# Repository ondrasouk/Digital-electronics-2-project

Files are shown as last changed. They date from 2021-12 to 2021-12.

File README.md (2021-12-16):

# WATER TANK CONROLLER

### Team members

* Ondřej Soukeník (responsible for LCD keypad, MENU)
* Pavel Vaněk (responsible for Sensors)
* Michaela Ryšavá (responsible for RTC, Main file)
* Zdeňka Varmužová (responsible for Documentation)

Link to this file in your GitHub repository:

[https://github.com/ondrasouk/Digital-electronics-2-project](https://github.com/ondrasouk/Digital-electronics-2-project)

### Table of contents

* [Project objectives](#objectives)
* [Hardware description](#hardware)
* [Libraries description](#libs)
* [Main application](#main)
* [Video](#video)
* [References](#references)

## Project objectives

* the task:
    * Water tank controller. The following can be used: water level measurement, pump control, rain sensor and others.
    * [Link](https://github.com/tomas-fryza/Digital-electronics-2/tree/master/Labs/project) to the task.

* to do:
    * Preparation
        * [x] Block structure design
        * [x] The split of work
    * Realization
        * [x] Use of sensors
        * [x] Individual blocks of code
        * [x] Verification of the functionality
        * [x] Generating HEX file
    * Presentation
        * [x] Documentation
        * [x] Discussion of results
        * [x] Video presentation

* done:
    * Irrigation system. Water level - controlling sensor is placed in the tank and measures the water level (5 levels). Sensor for measuring soil moisture is placed in a soil and both send data to control logic, where are evaluated. If there is enough water in the tank and soil moisture is under specific value, water pump is activated. After certain time period another measuring is made. User can choose from three modes of irrigation. More info about the system is in the [video](https://youtu.be/Qcah5Nm7IAs).

## Hardware description

The solution is designed on an Arduino Uno board with sensors and a water pump connected to external pins.

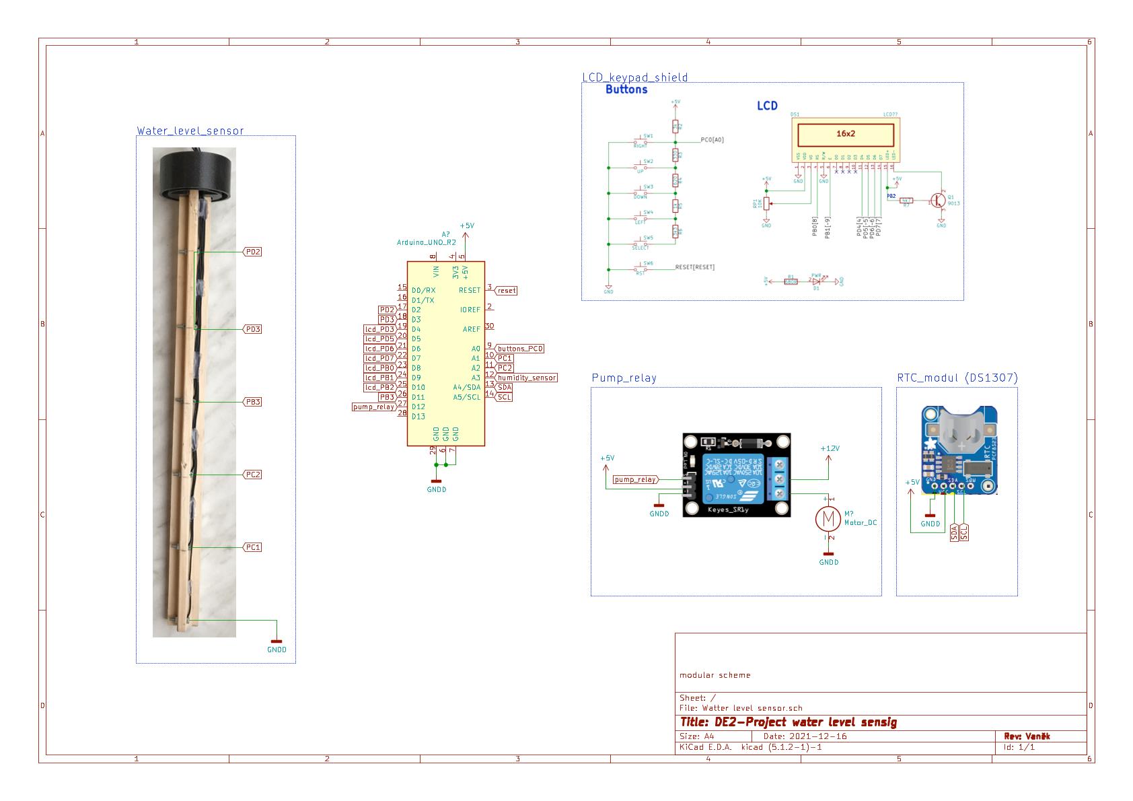
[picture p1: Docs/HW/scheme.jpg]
Scheme of connection


### Arduino Uno board 
The project is made for application on an Adruino Uno board with ATmega328P. 
[Arduino Uno board](Docs/arduino_shield.pdf)

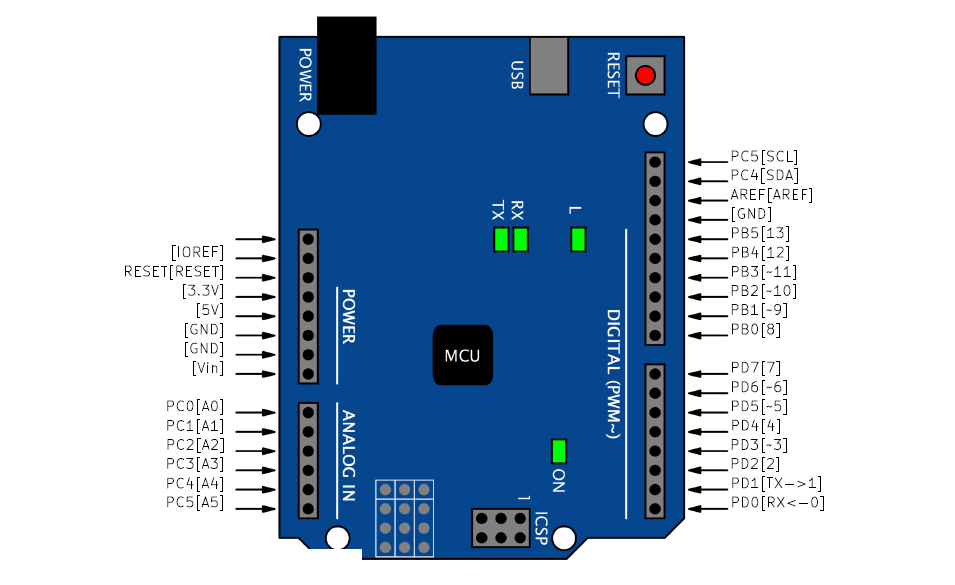
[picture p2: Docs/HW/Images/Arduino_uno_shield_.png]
Arduino_uno_board


For more informations see [hardware documentation](Docs/HW/readme.md).

### LCD keypad Shield
LCD and buttons are used for moving in the menu and displaying measured values. The LCD keypad shield is compatible with Arduino board.
[LCD keypad Shield](Docs/arduino_shield.pdf)
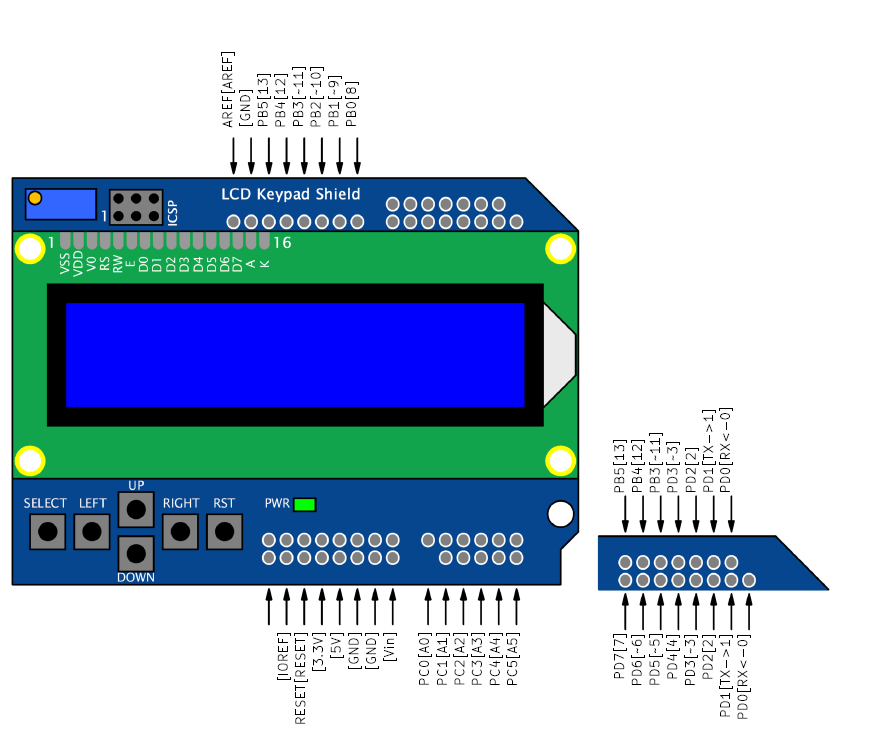
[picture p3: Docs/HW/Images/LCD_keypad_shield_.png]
LCD_keypad_shield


For more informations see [hardware documentation](Docs/HW/readme.md).

### Water lever sensor
The solution contains five sensors working on a resistive basis, which are placed on a panel. The top of the panel is attached to the lid of a canister with water. Six wires are brought out of the main board to the panel. One is for the reference (ground), other five are each in different height. The sensor contact surfaces are stainless steel screws placed on the panel. 

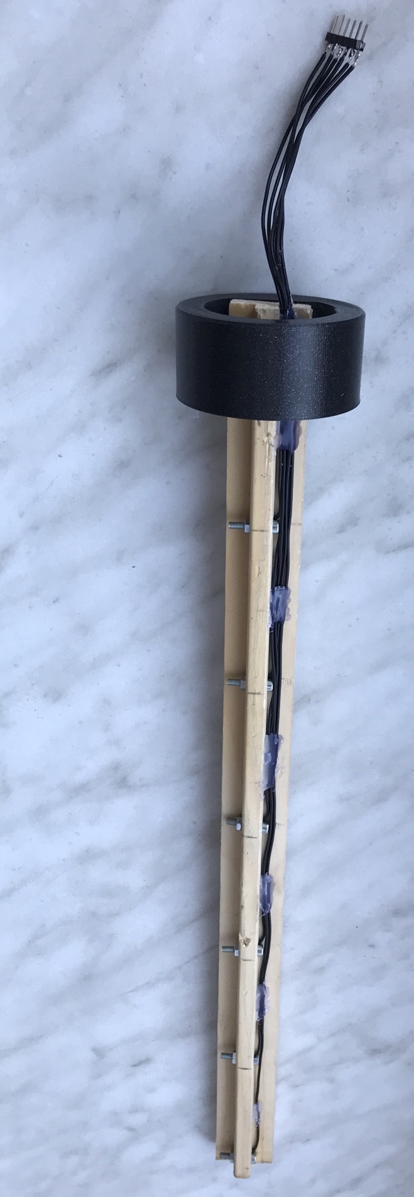
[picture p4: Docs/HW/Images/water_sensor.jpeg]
Water_level_sensor


For more informations see [hardware documentation](Docs/HW/readme.md).

### Soil moisture sensor
The sensor is based on different conductivities of the soil according to the moisture of the soil. Two wires are connected to the nails, which are placed in the soil. The resistivity is evaluated in central logic.

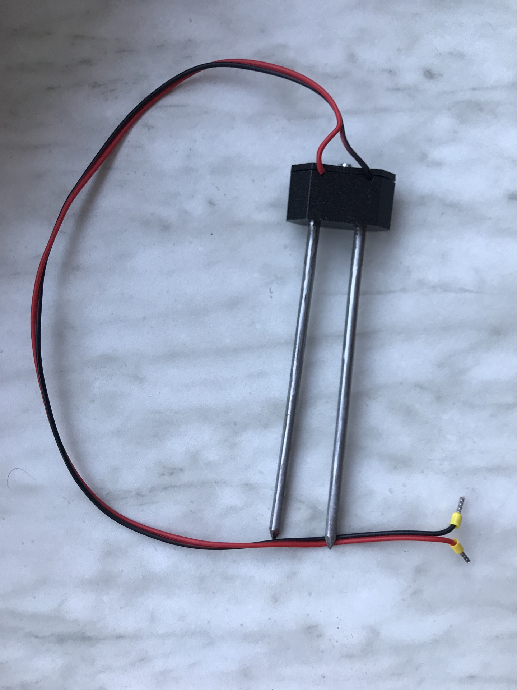
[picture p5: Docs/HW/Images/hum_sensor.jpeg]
Soil_moisture_sensor


For more informations see [hardware documentation](Docs/HW/readme.md).

For preventing nails from quick corrosion due to electrolysis is the internal pullup resistor switched only when measuring is done.

### Water pump
Water pumping is solved by ELEGANT's submersible pump with 12 V DC and 2,2 A input. The pump is designed for hoses with 10 mm inner diameter, which is suitable for the purposes for our project.

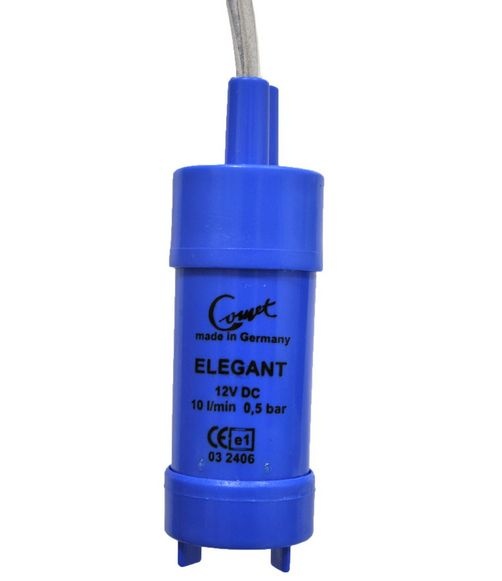
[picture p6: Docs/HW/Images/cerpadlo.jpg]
water_pump


For more informations see [hardware documentation](Docs/HW/readme.md).
NOTE: Testing has been done with another water pump. The pump mentioned above is only intended.

### Pump switching
Pump switching module is made with a relay. It can switches at 250 V up to 10 A.

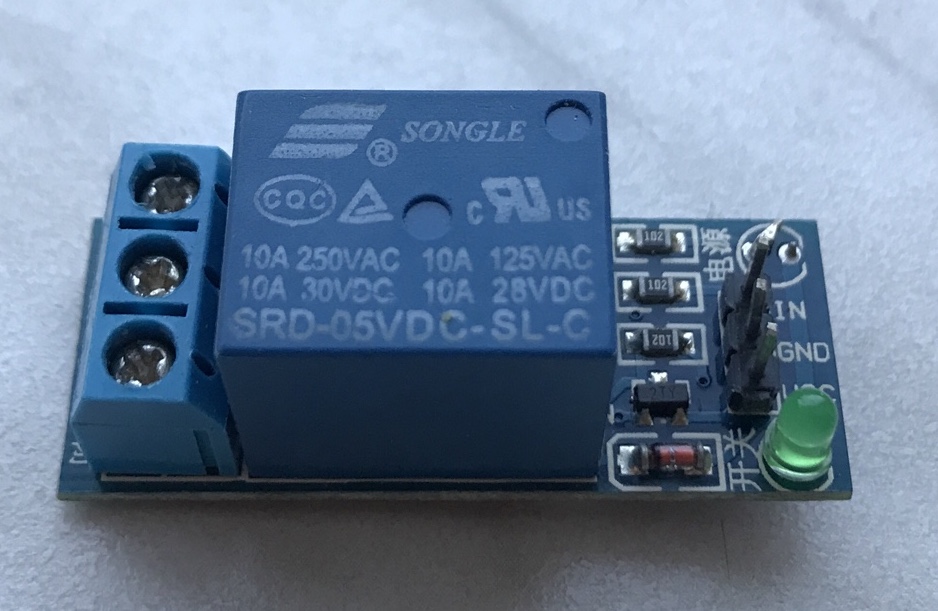
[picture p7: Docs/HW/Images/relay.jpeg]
Pump_switching


For more informations see [hardware documentation](Docs/HW/readme.md).

## Libraries description
For more info see the doxygen documentation.

### ``` timer.h ```
* Contains macros for controlling the timer modules.
* Template code is made by Tomas Fryza, BUT.
* Finished by Ondrej Soukenik.

### ``` uart.h ```
* Used to transmit and receive data through the built in UART.
* Author - Peter Fleury.

### ``` lcd.h ```
* Constains routines for interfacing a HD44780U-based character LCD display.
* Author - Peter Fleury.

### ``` lcd_buttons.h ```
* Includes function for button debouncing and button detection.

### ``` lcd_definitions.h ```
* Adjust the display settings.
* Author - Peter Fleury (Tomas Fryza, BUT).

### ``` level_sens.h ```
* Contains functions for initialising and reading data from water level sensors.

### ``` hum_sens.h ```
* Consist rutines to work with soil humidity sensor.

### ``` rtc.h ```
* This library was taken over and used with rtc module.

## Main application

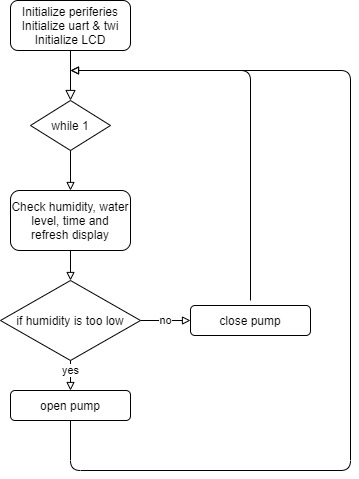
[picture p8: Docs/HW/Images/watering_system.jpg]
watering system scheme


## Video

[Link to video](https://youtu.be/Qcah5Nm7IAs)

## References

1. Arduino Uno and LCD keypad shield [schematic](Docs/arduino_shield.pdf)
2. ATmega328P [datasheet](Docs/ATmega328P_Datasheet.pdf)
3. LCD Keypad Shield [datasheet](Docs/Datasheet_DFR0009_D-Robotics.pdf)
4. [Relay](Docs/Datasheet_SRD-12VDC-xx-x_ETC.pdf) used for pump switching
5. Elegant submersible pump [datasheet](Docs/Datasheet_comet-pumpen-elegant.pdf)

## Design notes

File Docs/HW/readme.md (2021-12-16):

# Hardware documentation 

## Arduino Uno board
The basis is formed on an microrontroller board called Arduino Uno based on the ATmega328P ([datasheet](../ATmega328p_Datasheet.pdf)). It has 20 digital (input or output) pins and runs with 16 Mhz frequency. The power supply and data tranfer is solved by USB connection with PC.

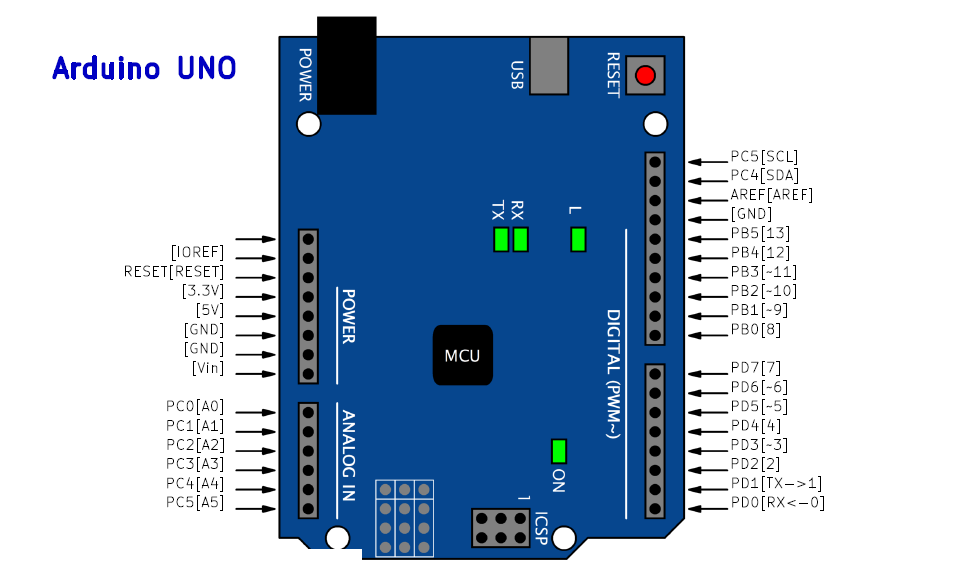
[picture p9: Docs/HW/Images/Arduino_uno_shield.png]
Arduino_uno_board


# LCD keypad Shield
The LCD Keypad Shield  is compatible with Arduino boards. It consists of a 1602 white character blue backlight LCD. The keypad consists of 5 keys (select, up, right, down and left). For reading the key value only one ADC channel is used, the evaluation is performed with the help of five stage voltage divider. 
[See datasheet here.](../Datasheet_DFR0009_D-Robotics.pdf)
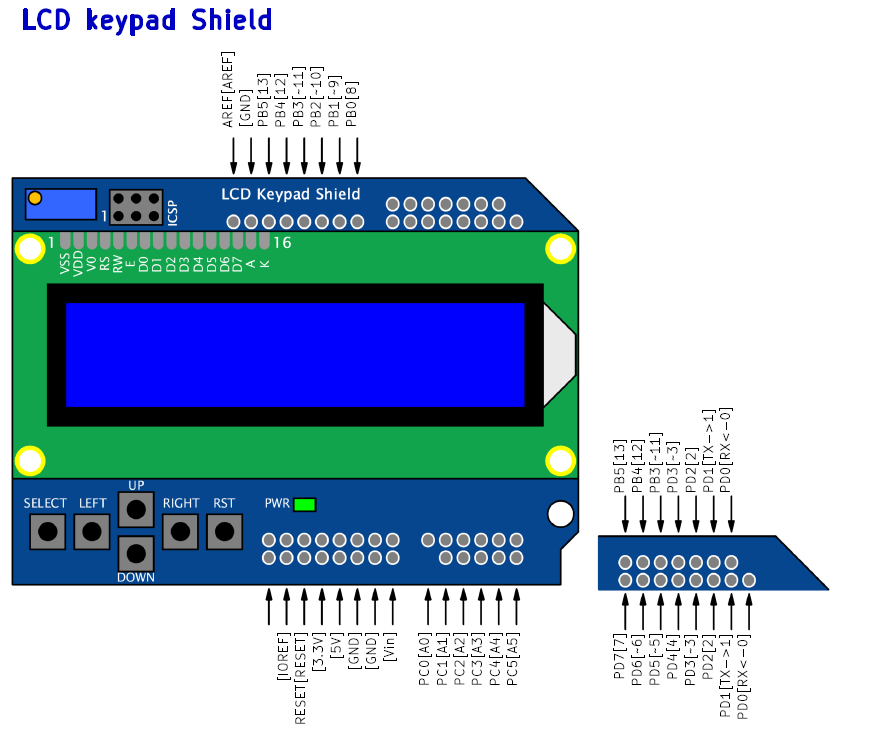
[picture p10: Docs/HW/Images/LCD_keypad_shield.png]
LCD_keypad


## Water level sensor
There are five sensors working on resistive basis. When we are using a canister with a volume of 25 litres, sensor registers changes after every five litres. Each sensor distinguishes only two states. (According to practical testing, there is no problem with water resistivity.)
For testing purposes and practital use a 40 cm long wooden bar has been made. In the bar are 6 holes made for stainless steel screws used as sensors contact surfaces. Wires connect the output pins from arduino and the screws on a bar.
Plastic holder has been made for fixing the sensor in the canister. It is put in a tank neck and holds the bar in a certain position. 3D model is available [here](3D_models/water_sensor_housing.stl).

sensor_water_level

## Soil moisture sensor
Sensor for soil moisture scanning is made as a resistive probe. Two wires are brought out of the main board and connected to nails. The nails are put in a soil and make the main part of the sensor. We watch resistance changes between the wires, it reaches from 0 to 10kOhm/cm. The second resistance of the divider is made out of pullup resistor in MCU and it's range is from 30 to 50kOhm.

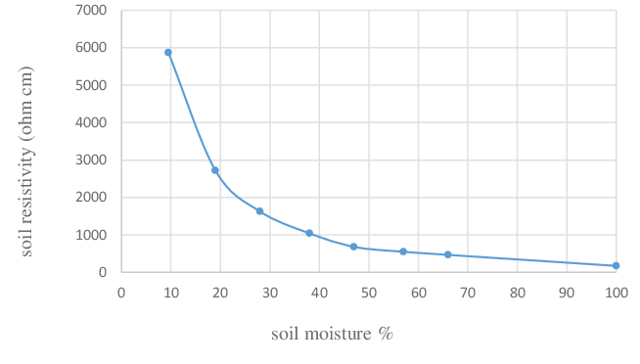
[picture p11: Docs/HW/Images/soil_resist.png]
soil_resistance_graph


It is enough to aproximate this dependence with linear course. A programmer has to set two calibration values, one for 0 % and one for 100 %.

sensor_soil_moisture
We need also to keep the spacing between the two contacts (nails). To solve that problem, a plastic holder has been made. It keeps the nails in certain position and data is not affected by improper handling. The 3D model for the socket is available [here](3D_models/humidity_sensor_housing_socket.stl) and for the lid [here](3D_models/humidity_sensor_housing_lid.stl).

### Corrosion protection
The nails are made out of steel, which are subjected to quick corrosion. Electrolysis significantly helps to cause the corrosion and in the sensor there is a direct current (DC) flowing on the surface. The solution is an internal pullup resistor, switched only when measuring is done. The process of corrosion is therefore slowed down. 

## Water pump
The water pump intended for this project for pumping water into a flowerpot is made by COMET-pumpen. It is a submersible pump with 12 V DC input voltage.The maximum throughput is 10l/min and it can run up to 500 hours. For more dails see the [datasheet](../Datasheet_comet-pumpen-elegant.pdf).
water_pump

## Pump switching
Pump swithing is solved by module with relay. The relay can switches at 250 V up to 10 A. The pump is suposed to has it's own power supply system. The details of relay are available [here](../Datasheet_SRD-12VDC-xx-x_ETC.pdf).
relay

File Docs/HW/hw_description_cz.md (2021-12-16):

# Dokumentace HW
## Snímání hladiny v nádrži
Při řešení typu snímání hladiny v úvahu přicházely tři řešení:
* Ultrazvukové snímání hladiny
* Tenzometrické (tlakové) snímání hladiny
* Rezistivní snímání hladiny

Žhavým adeptem bylo tenzometrické snímání. Je totiž velmi spolehlivé a zároveň i velice přesné. Jeho sonda je válcovitého tvaru a nechá se ponořit do nádrže. Výstupem je proudová smyčka a obvykle bývá navržena na průmyslový standard 20 mA. Ultrazvukové řešení bylo nevhodné z hlediska krytí. Osobně s tím v tomto případě mám špatnou zkušenost. 

Protože plánujeme školní projekt využít v reálné situaci, bylo nakonec vybráno snímání hladiny pomocí rezistivních snímačů. Voda v nádrži při určité hladině zkratuje dva kontakty, které uzavřou elektrický obvod. Řešení je jednoduché a snadno implementovatelné. Jeho nevýhodou je nízké rozlišení. Tenzometrické snímání nepřipadá v úvahu, protože je vhodné pro hloubky alespoň od 1m.

Senzorů bylo v našem řešení použito celkem 5. Jako nádoba byl dostupný 25 litrový barel. Proto naše rozlišení je cca 5l.

Pro testování i provoz byla vyrobena asi 40cm dlouhá dřevěná lišta do které bylo navrtáno 6 (5+GND) otvorů pro nerezové šroubky vytvářející kontaktní plochy senzorů. Pro ukotvnení v hrdle nádrže byl vytisknut z PETG plastu díl který se nasadí na hrdlo a ukotví tak lištu v kolmé pozici. Zároveň je v hrdle dostatek místa pro vyvedení hadičky na vodu (případně kabeláž ponorného čerpadla)

 Model v .stl formátu je dostupný ve složce 3D_models. Pokud se systém v provozu osvědčí, pro lepší životnost dřevěná lišta bude nahrazena PVC trubkou.

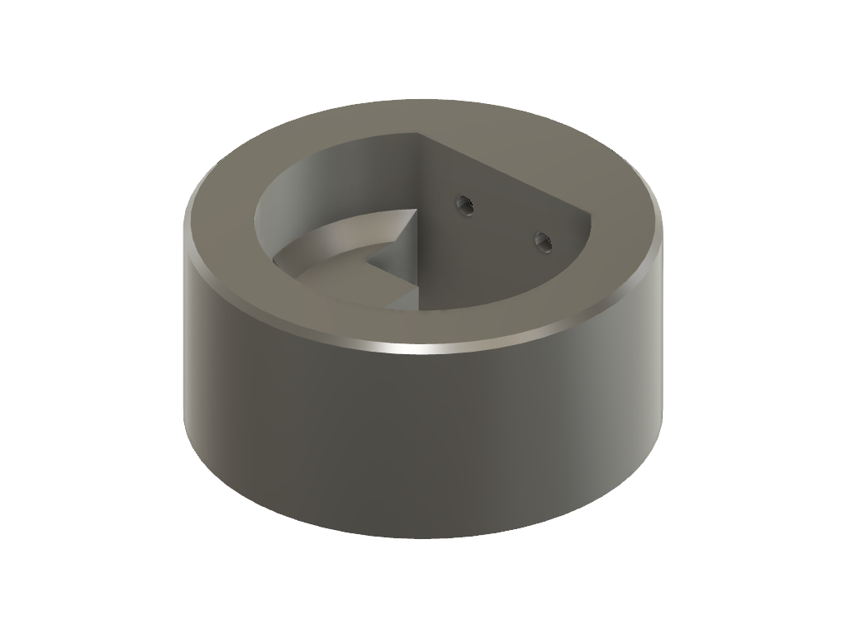
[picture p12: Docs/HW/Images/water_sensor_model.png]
sonda_model

sonda

## Snímání vlhkosti půdy
Snímání vlhkosti půdy je řešeno rezistivní sondou. Sonda byla vytvořena ze dvou mohutných hřebíků.  Opět pokud se řešen osvědčí, bude sonda vyrobená z nerezové oceli, pro lepší životnost. 

Odporová změna mezi sondami probíhá cca od 0-10kOhm/cm v závislosti na vlhkosti půdy. Druhý odpor děliče tvoří pro jednoduchost pullup rezistor v MCU. Ten má velikost od 30-50kOhm viz graf (zdroj researchgate.net/f).

graf

Pro účely zalévání bohatě postačuje vytvoření linneární aproximace této závislosti(stejně se totiž používá zejména ta linearnější část). Programátor pouze v hlavičkovém souboru zadá dvě kalibrační hodnoty (pro 0% a pro 100% vlhkosti)

Pro ukotvení sondy byl vytisknut přípravek zprostředkující vhodný odstup sond a kontakt k přívodům.

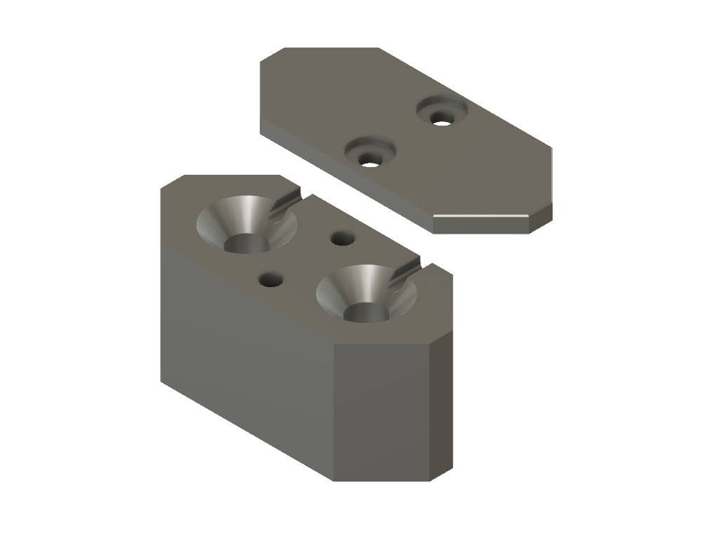
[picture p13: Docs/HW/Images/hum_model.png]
model2


Níže je pohled na konstrukci sondy
humsens

### Antikorozní ochrana
Protože sondy (hřebíky)jsou z běžné oceli (jinak se používají nerezové trny), může docházek ke korozi. Elektrolýza velmi výrazně napománá ke vzniku koroze na povrchu vodičů jimiž proudí DC proud. Ke zpomalení vlivu koroze se tedy vnitřní pullup rezistor připíná pouze při měření.

## Spínání čerpadla
Pro univerzálnost použitého čerpadla byl použit relátkový modul. Relé může spínat při 250V až 10A. V naší realizaci se počítá s DC čerpadlem, napájený vlastním systémem.

Modul relé přímo na desce má implementovaný proudový posilovací tranzistor. Jeho připojení k vývojové desce Arduino je tak velmi snadné.
relay

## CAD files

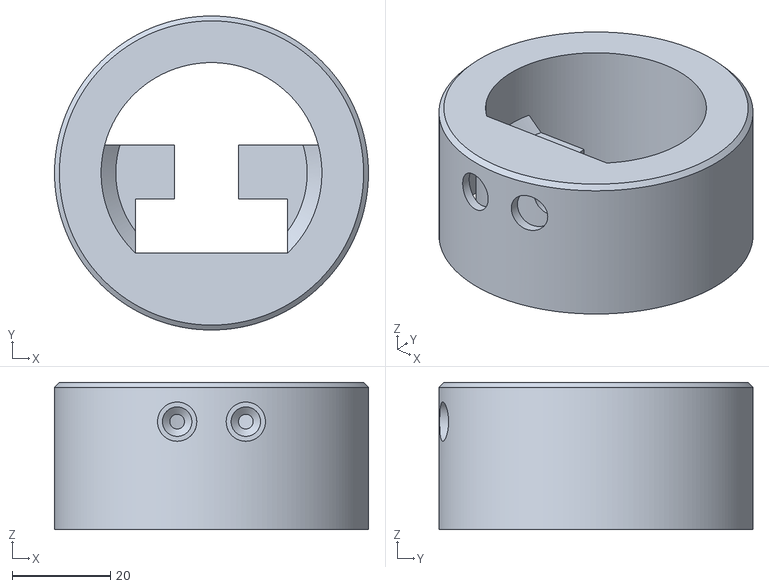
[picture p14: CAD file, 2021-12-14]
Docs/HW/3D_models/water_sensor_housing.stl
64.0 x 64.0 x 30.0

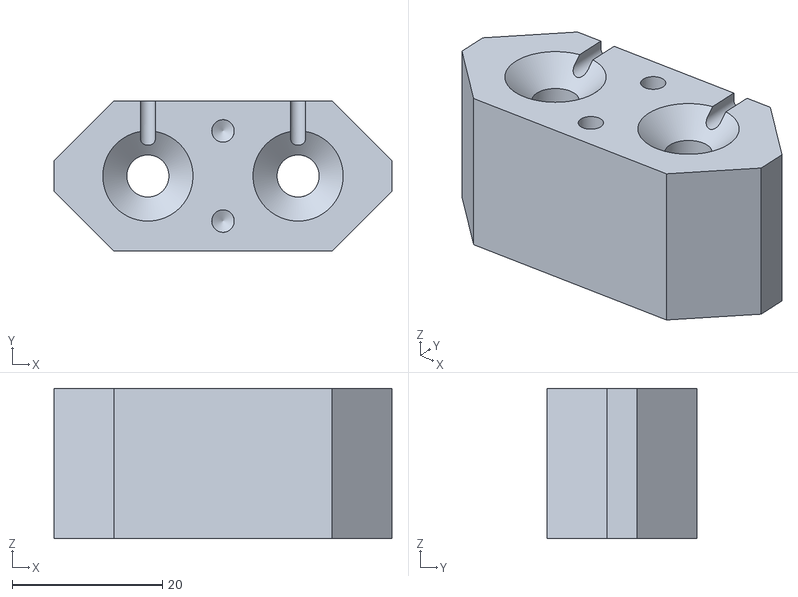
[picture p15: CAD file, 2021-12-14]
Docs/HW/3D_models/humidity_sensor_housing_socket.stl
45.0 x 20.0 x 20.0

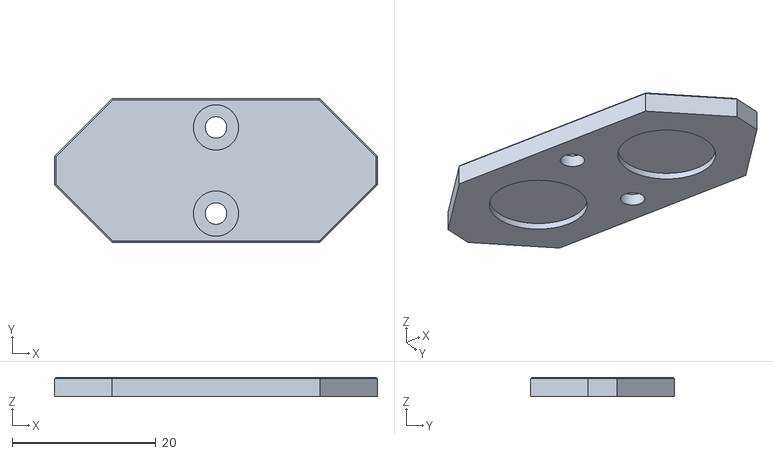
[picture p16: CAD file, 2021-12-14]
Docs/HW/3D_models/humidity_sensor_housing_lid.stl
45.0 x 20.0 x 2.70

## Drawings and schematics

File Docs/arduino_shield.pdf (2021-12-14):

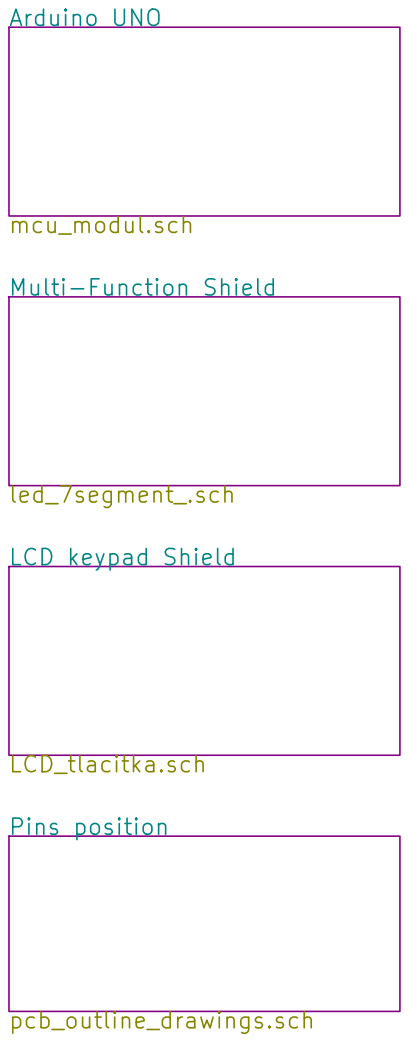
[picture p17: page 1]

File: arduino_shield.sch Sheet: / Brno University of Technology, Czechia

Id: 1/5 Title: Arduino boards

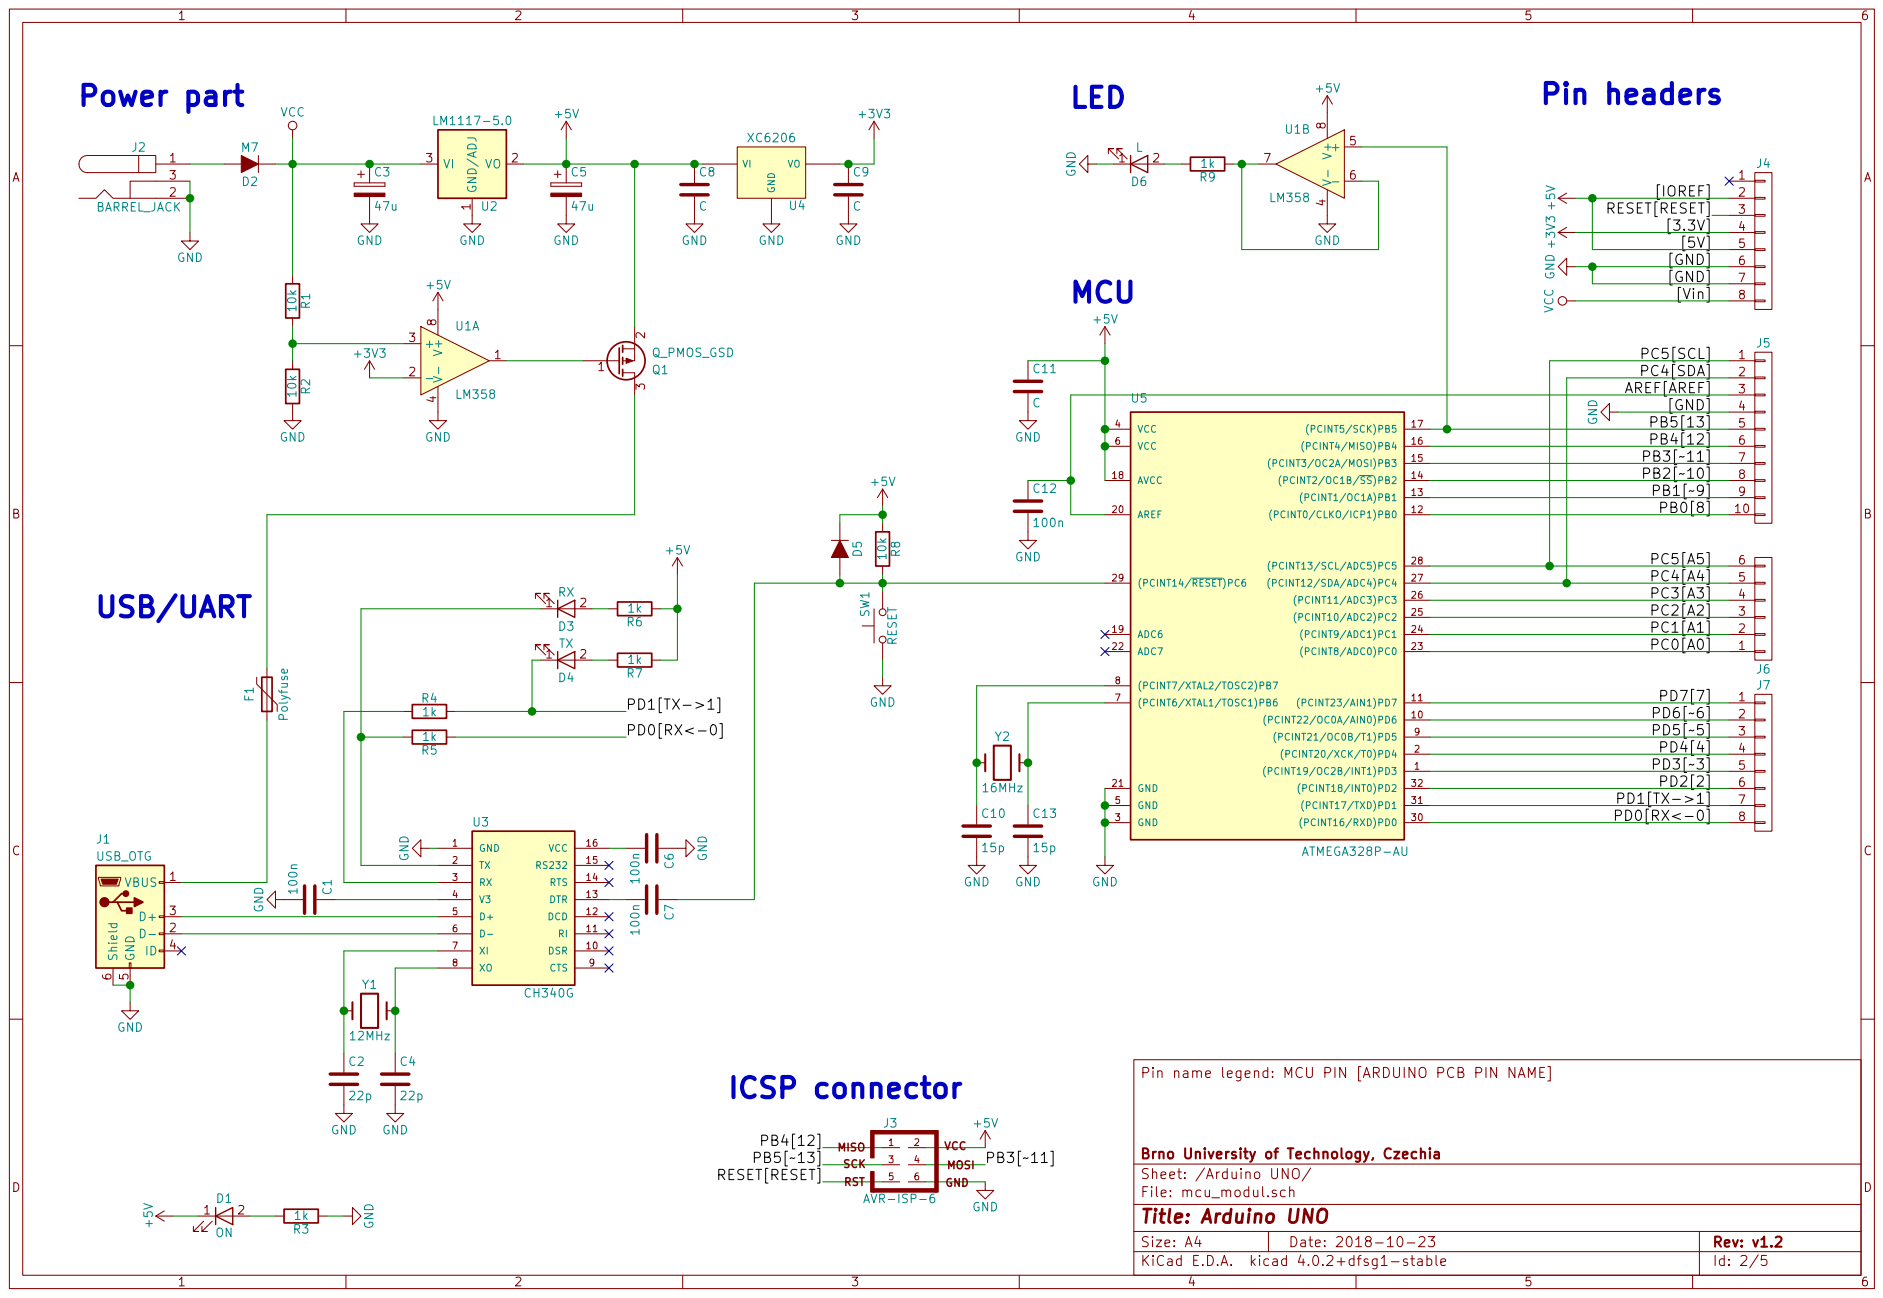
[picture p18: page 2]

RESET[RESET] +3V3 GND VCC

[GND] | 6
[GND] | 7
[Vin] | 8

PC4[SDA] | 2

PB4[12] | 6
PB3[11] | 7
PB2[10] | 8
PB1[9] | 9
PB0[8] | 10

PC4[A4] | 5
PC3[A3] | | 4
PC2[A2] | | 3

(PCINT6/XTAL1/TOSC1)PB6 7

PD4[4] | 4
PD3[3] | 5
PD2[2] | 6
PD1[TX->1] | 7
PD0[RX<-0] | 8

Pin name legend: MCU PIN [ARDUINO PCB PIN NAME]

File: mcu_modul.sch Sheet: /Arduino UNO/ Brno University of Technology, Czechia

Id: 2/5 Title: Arduino UNO

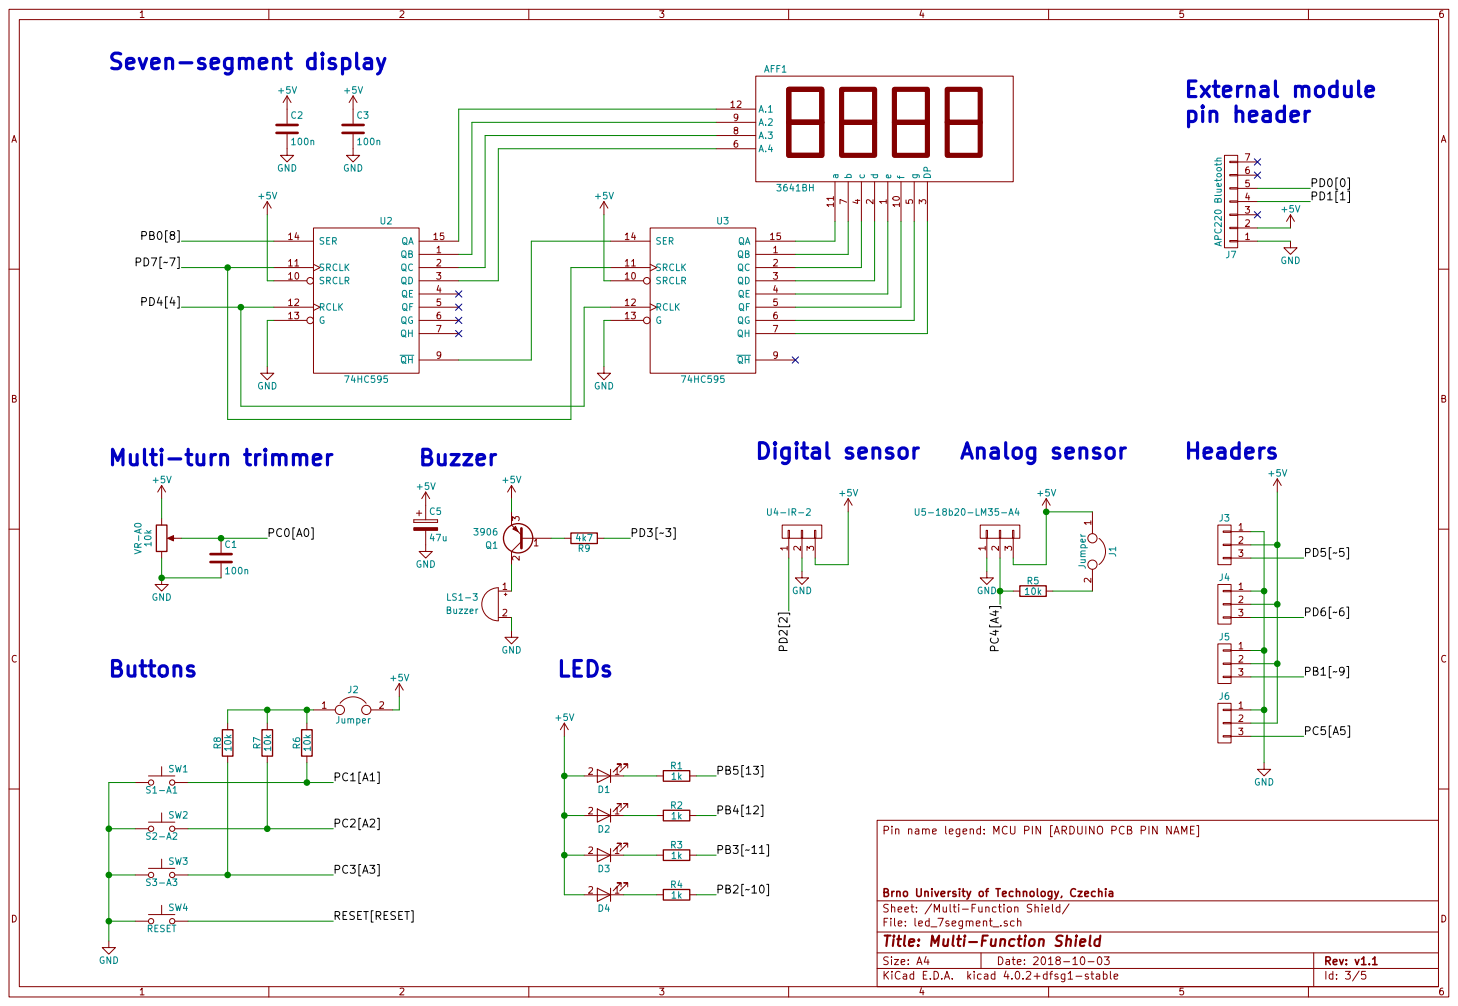
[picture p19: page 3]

Pin name legend: MCU PIN [ARDUINO PCB PIN NAME]

File: led_7segment_.sch Sheet: /Multi-Function Shield/ Brno University of Technology, Czechia

Id: 3/5 Title: Multi-Function Shield

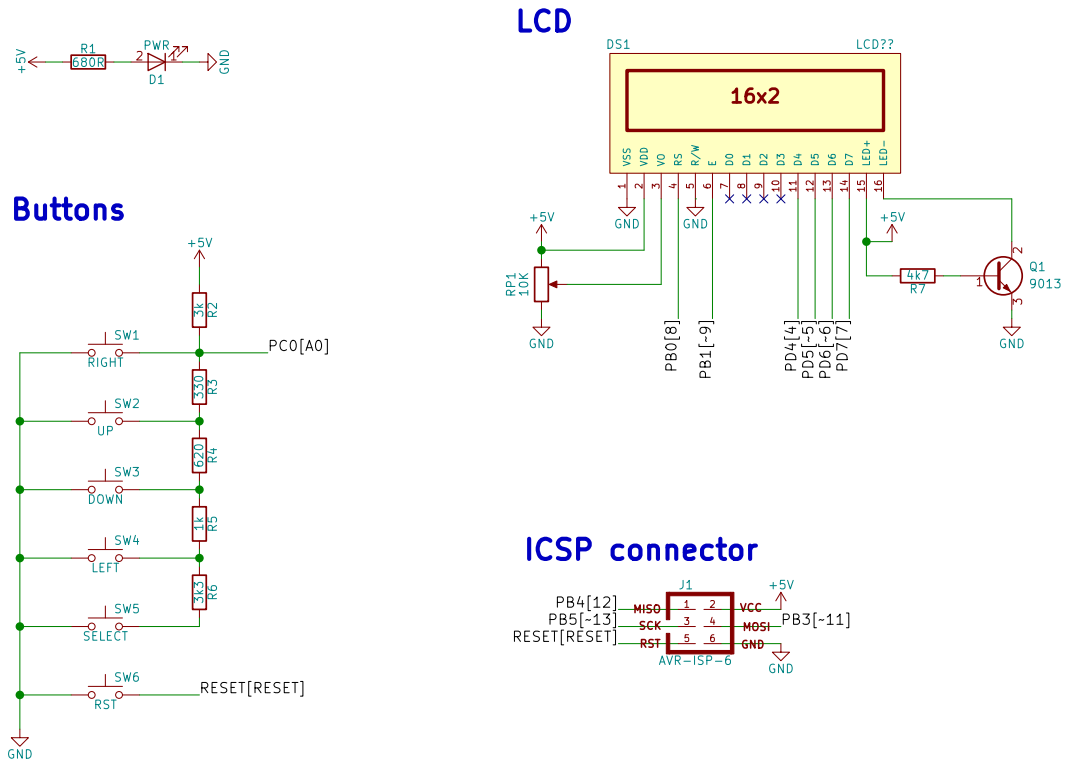
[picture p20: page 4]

Pin name legend: MCU PIN [ARDUINO PCB PIN NAME]

Brno University of Technology, Czechia
Sheet: /LCD keypad Shield/
File: LCD_tlacitka.sch
Id: 4/5 Title: LCD keypad Shield

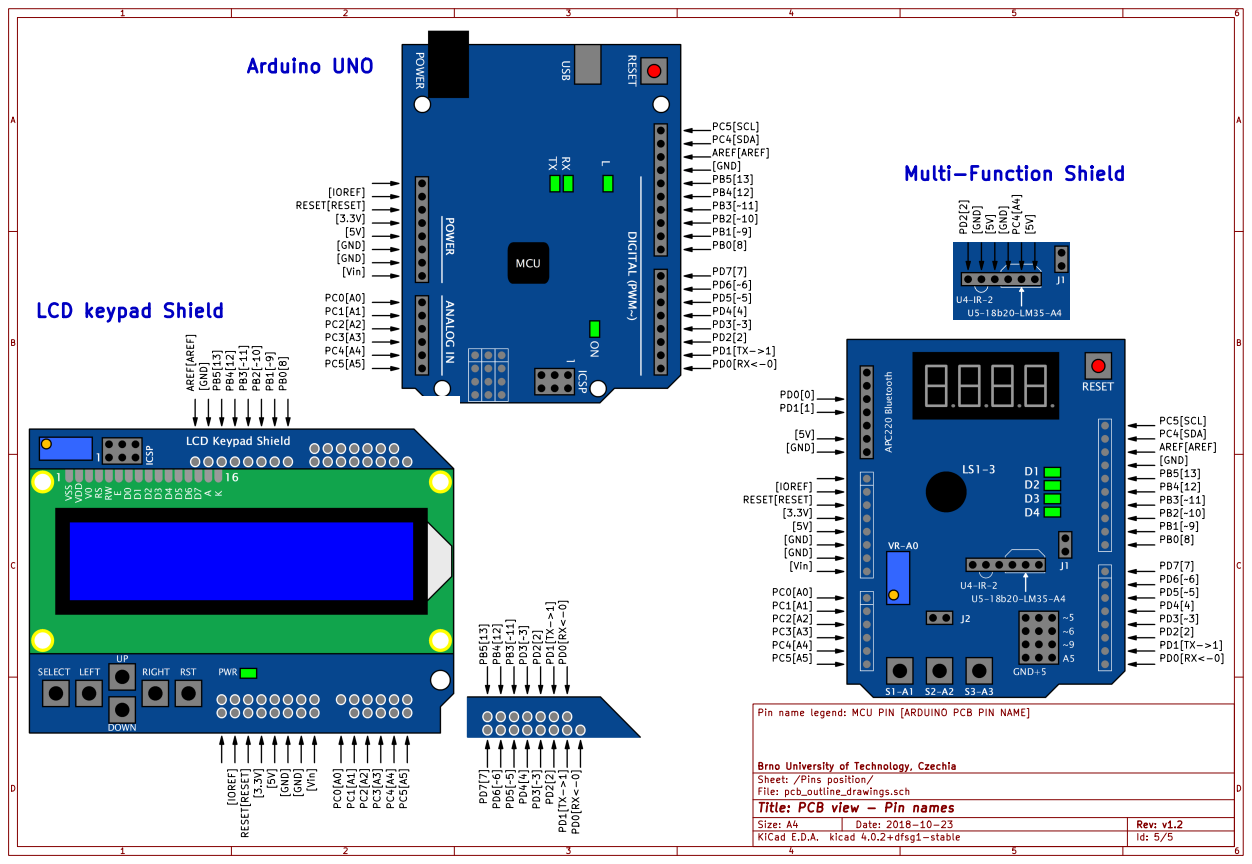
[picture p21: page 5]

Pin name legend: MCU PIN [ARDUINO PCB PIN NAME]

Brno University of Technology, Czechia
Sheet: /Pins position/
File: pcb_outline_drawings.sch
Id: 5/5 Title: PCB view - Pin names

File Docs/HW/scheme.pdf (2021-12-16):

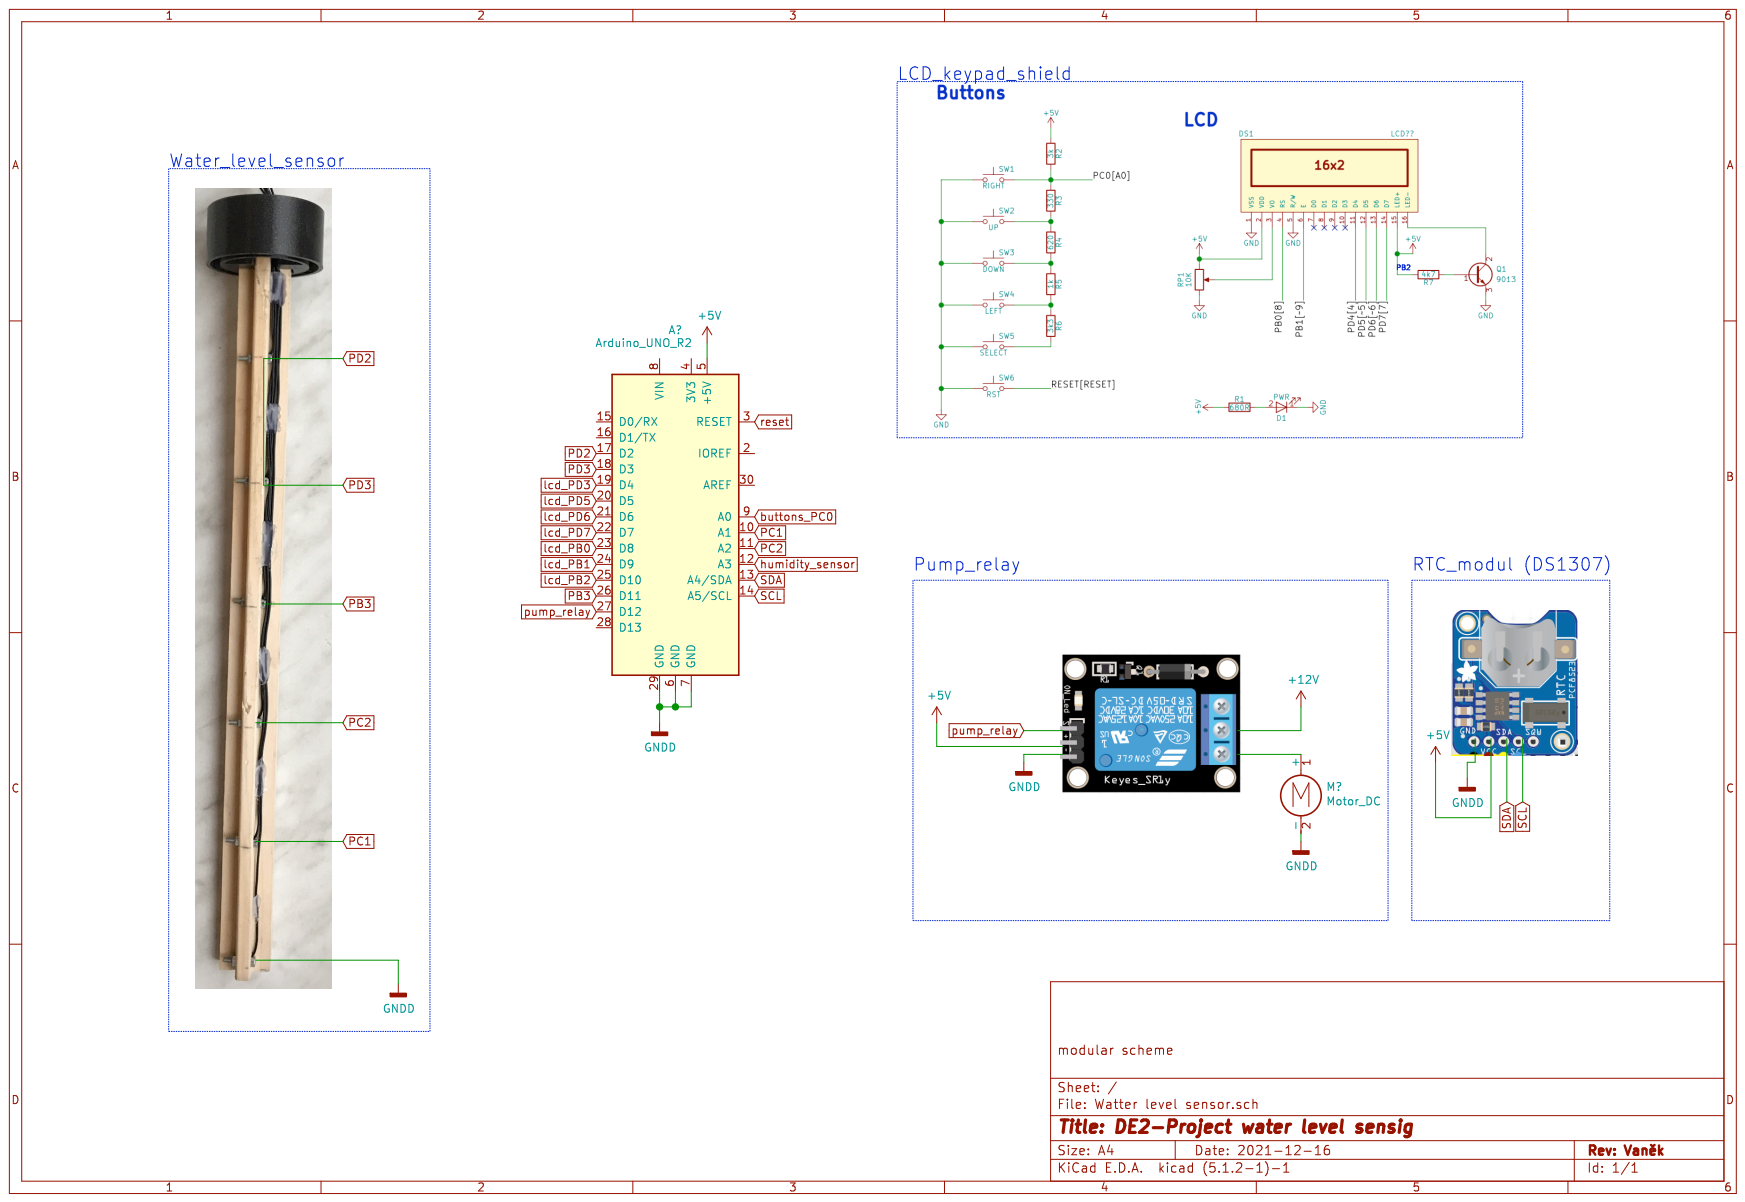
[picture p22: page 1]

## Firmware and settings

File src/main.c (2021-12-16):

/***********************************************************************
 * 
 * Analog-to-digital conversion with displaying result on LCD and 
 * transmitting via UART.
 * ATmega328P (Arduino Uno), 16 MHz, AVR 8-bit Toolchain 3.6.2
 *
 * Copyright (c) 2018-Present Tomas Fryza
 * Dept. of Radio Electronics, Brno University of Technology, Czechia
 * This work is licensed under the terms of the MIT license.
 * 
 **********************************************************************/
 /**
  * @file main.c
  * @author Ondrej Soukenik
  */ 

/* Includes ----------------------------------------------------------*/
#include <avr/io.h>         // AVR device-specific IO definitions
#include <avr/interrupt.h>  // Interrupts standard C library for AVR-GCC
#include <util/atomic.h>    // Atomic operations
#include <stdlib.h>         // C library. Needed for conversion function
#include <stdio.h>
#include <util/delay.h>
#include <string.h>
#include "timer.h"          // Timer library for AVR-GCC
#include "lcd.h"            // Peter Fleury's LCD library
#include "uart.h"           // Peter Fleury's UART library
#include "lcd_buttons.h"    // Library with reading buttons
#include "hum_sens.h"
#include "level_sens.h"
#include "rtc.h"
#include "twi.h"

/* Definitions -------------------------------------------------------*/
#define DISPLAY_ROWS 2
#define MENU_TEXT_SIZE_D 10
#define MENU_TEXT_SHIFT_TIME_USEC 400000
#define MENU_ITEM_SIZE_D 5
#define TIM2_OVERFLOW_TIME 16384
#define MENU_TIMEOUT_USEC 10000000

#define pump_pin PINB
#define pump_port &PORTB
#define pump_gpio 4
#define pump_ddr &DDRB

#if !defined(ARRAY_SIZE)
    #define ARRAY_SIZE(x) (sizeof((x)) / sizeof((x)[0]))
#endif
#define CURSOR_POS (menu_pos + scroll_pos)
#define MENU_TEXT_SHIFT_NUM MENU_TEXT_SHIFT_TIME_USEC / TIM2_OVERFLOW_TIME
#define MENU_TIMEOUT_NUM MENU_TIMEOUT_USEC / TIM2_OVERFLOW_TIME

/*--------------------------------------------------------------------*/
/* Globals -----------------------------------------------------------*/
/*--------------------------------------------------------------------*/
/**
 * @brief Custom character definition
 */
/* Custom Characters -------------------------------------------------*/
// Custom character definition using https://omerk.github.io/lcdchargen/
const uint8_t customChar[] = {
    0b11000, 0b11100, 0b10110, 0b10011, 0b10011, 0b10110, 0b11100,
    0b11000, // 0
    0b10000, 0b11000, 0b11100, 0b11110, 0b11110, 0b11100, 0b11000,
    0b10000, // 1
    0b10000, 0b10000, 0b10000, 0b10000, 0b10000, 0b10000, 0b10000,
    0b10000, // 2
    0b11000, 0b11000, 0b11000, 0b11000, 0b11000, 0b11000, 0b11000,
    0b11000, // 3
    0b11100, 0b11100, 0b11100, 0b11100, 0b11100, 0b11100, 0b11100,
    0b11100, // 4
    0b11110, 0b11110, 0b11110, 0b11110, 0b11110, 0b11110, 0b11110,
    0b11110, // 5
    0b11111, 0b11111, 0b11111, 0b11111, 0b11111, 0b11111, 0b11111,
    0b11111, // 6
};

/* Characters for type -----------------------------------------------*/
// "\xHH" for entering plain hexadecimal values (0-9 is user defined symbols)
const char type_suffix[5] = "  %ms";

/* Structures definitions --------------------------------------------*/
/**
 * @ingroup lcd
 * @brief structure for menu
 */ 
typedef struct {
    const uint8_t type; // 1 - plain; 2 - with "%"; 3 - with "m"; 4 - with "s"; higher is character menu items
    const uint8_t limit_min;
    const uint8_t step;
    const uint8_t limit_max;
    uint8_t *value;
} item_uint8;

/* Time --------------------------------------------------------------*/

uint8_t time_hours = 0;
uint8_t time_minutes = 0;
uint8_t time_seconds = 0;

/* Menu --------------------------------------------------------------*/

uint8_t irrigation_mode = 0; // Variable with what menu to display

const char *menu_head_items[] = {
    "smart",
    " drip",
    "const",
    " time",
};

const char *smart_menu[] = {
    "Irrigation mode:",
    "Days away:",
    "Irrigation level:",
    "Save water from water level:",
};

uint8_t days_away = 3;
uint8_t irrigation_level = 50;
uint8_t save_water_level = 20;

const item_uint8 smart_menu_items[] = {
    {5, 0, 1, ARRAY_SIZE(menu_head_items)-1, &irrigation_mode},
    {1, 1, 1, 14, &days_away},
    {2, 0, 10, 100, &irrigation_level},
    {2, 0, 20, 100, &save_water_level},
};

const char *drip_menu[] = {
    "Irrigation mode:",
    "Max irrigation level:",
    "Min irritation level:",
    "Irritation (mins):",
};

uint8_t irrigation_max = 80;
uint8_t irrigation_min = 30;
uint8_t irrigation_duration_min = 20;

const item_uint8 drip_menu_items[] = {
    {5, 0, 1, ARRAY_SIZE(menu_head_items)-1, &irrigation_mode},
    {2, 10, 10, 100, &irrigation_max},
    {2, 0, 10, 100, &irrigation_min},
    {3, 0, 1, 255, &irrigation_duration_min},
};

const char *const_menu[] = {
    "Irrigation mode:",
    "Irritation level:",
    "Hysterezis:",
    "Irritation (mins):",
    "Wait (min):",
};

uint8_t irrigation_hysterezis = 20;
uint8_t irrigation_wait_min = 100;

const item_uint8 const_menu_items[] = {
    {5, 0, 1, ARRAY_SIZE(menu_head_items)-1, &irrigation_mode},
    {2, 1, 1, 14, &irrigation_level},
    {2, 10, 10, 100, &irrigation_hysterezis},
    {3, 0, 1, 255, &irrigation_duration_min},
    {3, 0, 1, 255, &irrigation_wait_min},
};

const char *time_menu[] = {
    "Irrigation mode:",
    "Hours:",
    "Minutes:",
};

const item_uint8 time_menu_items[] = {
    {5, 0, 1, ARRAY_SIZE(menu_head_items)-1, &irrigation_mode},
    {1, 0, 1, 23, &time_hours},
    {1, 0, 1, 59, &time_minutes},
};

const char **mode_menu_pointers[] = {
    smart_menu,
    drip_menu,
    const_menu,
    time_menu,
}; // Add all menus to display

const item_uint8 *mode_menu_items[] = {
    smart_menu_items,
    drip_menu_items,
    const_menu_items,
    time_menu_items,
};

const uint8_t mode_menu_lenght[] = {
    ARRAY_SIZE(smart_menu),
    ARRAY_SIZE(drip_menu),
    ARRAY_SIZE(const_menu),
    ARRAY_SIZE(time_menu),
};

const char **menu_character_values_pointers[] = {
    menu_head_items,
};

/* Display variables --------------------------------------------------*/

uint8_t menu_pos = 0;   // position of top item in menu (0 - x)
uint8_t scroll_pos = 0; // line of cursor 0 or 1

uint8_t slice_start = 0;
const char *shift_string;
char shift_buffer[MENU_TEXT_SIZE_D + 1] = "         \x7e"; // last characters is left arrow + end of string
uint8_t scroll_pos_shift = 255;

char value_disp[MENU_ITEM_SIZE_D + 1] = "     ";

uint8_t display_update = 1; // 0 - no update in menu, 1 - update in menu, 2 - update in menu values, 3 - no update in status page, 4 - update in status page, 5 - update in status page values
uint8_t status_page = 0; // 0 - sensors readout, 1 - time

/* Global variables --------------------------------------------------*/

uint8_t TIM1_flag = 0;
uint8_t TIM2_flag = 0;
uint16_t TIM2_display_timer = 0;
uint16_t ADC_key_value = 65535;
uint16_t sens_humidity = 100;
uint8_t sens_water_level = 100;
uint8_t pump_state = 0; // 0 - off, 1 - running

/*--------------------------------------------------------------------*/
/*--------------------------------------------------------------------*/
/* Function definitions ----------------------------------------------*/
/*--------------------------------------------------------------------*/
/*--------------------------------------------------------------------*/

/*--------------------------------------------------------------------*/
/* Pump control Function definitions ---------------------------------*/
/*--------------------------------------------------------------------*/

/**
 * @ingroup pump
 * @brief Function starts watering
 */ 
void pump_start()
{
    *pump_port &= ~(1<<pump_gpio);
    pump_state = 1;
}
/**
 * @ingroup pump
 * @brief Function stops watering
 */ 
void pump_stop()
{
    *pump_port |= (1<<pump_gpio);
    pump_state = 0;
}
/**
 * @ingroup pump
 * @brief Function for watering - smart mode
 * @detail 
 */ 
void smart_mode() 
{
    if((sens_humidity < (unsigned) (irrigation_level - irrigation_hysterezis / 2)) & (sens_water_level != 0)){
        pump_start();
    }
    else{
        pump_stop();
    }
}
/**
 * @ingroup pump
 * @brief Function for watering drip mode
 * @detail
 */
void drip_mode() 
{
    if((sens_humidity < (unsigned) (irrigation_level - irrigation_hysterezis / 2)) & (sens_water_level != 0)){
        pump_start();
    }
    else{
        pump_stop();
    }
}
/**
 * @ingroup pump
 * @brief Function for watering constant mode
 * @detail
 */
void const_mode()
{
    if((sens_humidity < (unsigned) (irrigation_level - irrigation_hysterezis / 2)) & (sens_water_level != 0)){
        pump_start();
    }
    else{
        pump_stop();
    }
}

/**
 * @ingroup pump
 * @brief Function for switching between each modes
 * @detail
 */
void watering_mode(uint8_t mode){
    switch (mode)
    {
        case 0:
            smart_mode();
            break;
        case 1:
            drip_mode();
            break;
        case 2:
            const_mode();
            break;
        default:
            pump_stop();
    }
}

/*--------------------------------------------------------------------*/
/* Display Function definitions --------------------------------------*/
/*--------------------------------------------------------------------*/

/**
 * @ingroup lcd
 * @brief Function for cyclic increment of value
 * @details If value is greater than max value, function sets min value
 * @details Function is used for shifting menu
 * @param x pointer to x, line in nemu
 * @param lim_min minimum of range of x
 * @param lim_max maximum for range of x
 */ 
void cyclic_inc(uint8_t *x, const uint8_t lim_min, const uint8_t lim_max)
{
    uint8_t value = *x;
    *x = value + 1;
    if((*x > lim_max)|((*x - value) != 1)){
        *x = lim_min;
    }
}
/**
 * @ingroup lcd
 * @brief Function for cyclic decrement of value
 * @details If value is smaller than min value, function sets max value
 * @details Function is used for shifting menu
 * @param x pointer to x, line in nemu
 * @param lim_min minimum of range of x
 * @param lim_max maximum for range of x
 */
void cyclic_dec(uint8_t *x, const uint8_t lim_min, const uint8_t lim_max)
{
    uint8_t value = *x;
    *x = value - 1;
    if((*x < lim_min)|((value - *x) != 1)){
        *x = lim_max;
    }
}


/**
 * @ingroup lcd
 * @brief Function for increment of value in certain range
 * @details If value is greater than max value, function sets max value
 * @details Function is used for shifting menu
 * @param x pointer to x, line in nemu
 * @param lim_min minimum of range of x
 * @param lim_max maximum for rangl of x
 */ 
void limited_inc(uint8_t *x, const uint8_t lim, const uint8_t step)
{
    uint8_t value = *x;
    *x = value + step;
    if((*x > lim)|((*x - value) != step)){
        *x = lim;
    }
}
/**
 * @ingroup lcd
 * @brief Function for decrement of value in certain range
 * @details If value is grater than min value, function sets min value
 * @details Function is used for shifting menu
 * @param x pointer to x, line in nemu
 * @param lim_min minimum of range of x
 * @param lim_max maximum for range of x
 */ 
void limited_dec(uint8_t *x, const uint8_t lim, const uint8_t step)
{
    uint8_t value = *x;
    *x = value - step;
    if((*x < lim)|((value - *x) != step)){
        *x = lim;
    }
}

/**
 * @ingroup lcd
 * @brief Function for cutting string for scrolling long text
 * @param str pointer to string
 * @param buffer how long string can be displayed
 * @param start position in string from where it should be displayed
 */ 
void slice_str(const char *str, char *buffer, uint8_t start)
{
    strncpy(buffer, str + start, MENU_TEXT_SIZE_D - 1);
}

/**
 * @ingroup lcd
 * @brief Function for editing format of number
 * @details Function is used for displaying time
 * @details 1 -> "01"; 25 -> "25"
 * @param x number with time value
 * @param str output edited time value
 */
void itoa_with_starting_zero(uint8_t x, char *str) 
{
    if(x < 10){
        itoa(x, str+1, 10);
        str[0] = '0';
    }
    else if(x < 100){
        itoa(x, str, 10);
    }
}

/**
 * @ingroup lcd
 * @brief Function displaying time on LCD
 * @param x horizontal position
 * @param y vertical position
 * @param h hours value
 * @param m minutes value
 * @param s seconds value
 */
void display_time(uint8_t x, uint8_t y, uint8_t h, uint8_t m, uint8_t s) 
{
    char str[] = "  ";
    lcd_gotoxy(x, y);
    itoa_with_starting_zero(h, str);
    lcd_puts(str);
    lcd_puts(":");
    itoa_with_starting_zero(m, str);
    lcd_puts(str);
    lcd_puts(":");
    itoa_with_starting_zero(s, str);
    lcd_puts(str);
}

/**
 * @ingroup lcd
 * @brief Function for convert value to string with certain type
 * @param value value which should be converted to "type" type and saved in str
 * @param str pointer to output str variable
 * @param type type from structure
 */
void itoa_menu_item(int value, char *str, uint8_t type)
{
    strncpy(str, "     ", MENU_ITEM_SIZE_D); // Clear output buffer
    if(type < ARRAY_SIZE(type_suffix)){
        if(value < 10){
            itoa(value, str + MENU_ITEM_SIZE_D - 2, 10);
        }
        else if(value < 100){
            itoa(value, str + MENU_ITEM_SIZE_D - 3, 10);
        }
        else if(value < 1000){
            itoa(value, str + MENU_ITEM_SIZE_D - 4, 10);
        }
        else if(value < 10000){
            itoa(value, str + MENU_ITEM_SIZE_D - 5, 10);
        }
        else{
            itoa(value, str, 10);
        }
        str[4] = type_suffix[type];
    }
    else{
        if((type - ARRAY_SIZE(type_suffix)) < ARRAY_SIZE(menu_character_values_pointers)){
            strcpy(str ,menu_character_values_pointers[type-ARRAY_SIZE(type_suffix)][value]);
        }
        else{
            str = "error";
        }
    }
}

/**
 * @ingroup lcd
 * @brief Timer 1 routine
 * @details function checks sensors and update display
 * @details if needed, function call watering process
 */ 
void TIM1_routine() 
{
    if(TIM1_flag){
        char str[] = "     ";
        TIM1_flag = 0; // reset the flag
        sens_humidity = read_hum(); // read the humidity of soil
        sens_water_level = read_level(); // read the water level
        uart_puts("\n\rSoil Humidity: ");
        itoa_menu_item(sens_humidity, str, 2);
        uart_puts(str);
        uart_puts("\n\rWater level: ");
        itoa_menu_item(sens_water_level, str, 2);
        uart_puts(str);
        if(display_update == 3){
            display_update = 5;
        }
        if(status_page == 0){
            status_page = 1;
            display_update = 4;
        }
        else if(status_page == 1){
            status_page = 0;
            display_update = 4;
        }
        watering_mode(irrigation_mode);
    }
}

/**
 * @ingroup lcd
 * @brief Timer 2 routine
 * @details server for shifting long text in line
 */ 
void TIM2_routine() 
{
    if(scroll_pos_shift != 255){
        if (TIM2_flag > MENU_TEXT_SHIFT_NUM) {
            TIM2_flag = 0;
            if (slice_start > (strlen(shift_string) - MENU_TEXT_SIZE_D)){
                slice_start = 0;
                shift_buffer[MENU_TEXT_SIZE_D - 1] = 0x7e;
            }
            else if(slice_start == (strlen(shift_string) - MENU_TEXT_SIZE_D)){
                strncpy(shift_buffer, shift_string + slice_start, MENU_TEXT_SIZE_D);
            }
            slice_str(shift_string, shift_buffer, slice_start);
            lcd_gotoxy(1, scroll_pos_shift);
            lcd_puts(shift_buffer);
            
            slice_start++;
        }
    }
    else{
        TIM2_flag = 0;
    }
}

/**
 * @ingroup lcd
 * @brief Function for display one line of menu
 * @param menu_entries[] chosen menu
 * @param line line to display
 */ 
void menu_line_print(const char *menu_entries[], uint8_t line)
{
    lcd_gotoxy(1,line);
    if(strlen(menu_entries[menu_pos + line]) > MENU_TEXT_SIZE_D){
        slice_start = 0;
        slice_str(menu_entries[menu_pos + line], shift_buffer, 0);
        lcd_puts(shift_buffer);
        if(scroll_pos == line){
            shift_string = menu_entries[menu_pos + line];
            scroll_pos_shift = line;
        }
    }
    else{
        lcd_puts(menu_entries[menu_pos + line]);
    }
    lcd_gotoxy(11, line);
    itoa_menu_item(*mode_menu_items[irrigation_mode][menu_pos+line].value, value_disp, mode_menu_items[irrigation_mode][menu_pos+line].type);
    lcd_puts(value_disp);
}

/**
 * @ingroup lcd
 * @brief Function for displaying and scrolling in menu
 * @details function display start position of menu and redisplay lines when key for scrolling is pressed
 * @details when menu text is too long, it runs function for line scrolling
 * @param key_press define direction for scrolling
 */ 
void display_menu(uint8_t key_press)
{
    item_uint8 menu_item = mode_menu_items[irrigation_mode][CURSOR_POS];
    if(key_press == 3){ // UP Key
        scroll_pos++;
        if((menu_pos < mode_menu_lenght[irrigation_mode]-2) & (scroll_pos == 2)){ // scroll up
            menu_pos++;
            scroll_pos--;
            display_update = 1;
        }
        else if(scroll_pos == 2){ // top of menu
            scroll_pos--;
        }
    }
    else if(key_press == 4){ // DOWN Key
        scroll_pos--;
        if((menu_pos > 0) & (scroll_pos == 255)){ // scroll down
            menu_pos--;
            scroll_pos++;
            display_update = 1;
        } 
        else if (scroll_pos == 255){ // bottom of menu
            scroll_pos++;
        }
    }
    else if(key_press == 5){ // RIGHT Key
        if(menu_item.type >= ARRAY_SIZE(type_suffix)){
            cyclic_inc(menu_item.value, menu_item.limit_min, menu_item.limit_max);
        }
        else{
            limited_inc(menu_item.value, menu_item.limit_max, menu_item.step);
        }
        display_update = 2;
    }
    else if(key_press == 2){  // LEFT Key
        if(menu_item.type >= ARRAY_SIZE(type_suffix)){
            cyclic_dec(&irrigation_mode, menu_item.limit_min, menu_item.limit_max);
        }
        else{
            limited_dec(menu_item.value, menu_item.limit_min, menu_item.step);
        }
        display_update = 2;
    }
    lcd_clrscr();
    lcd_gotoxy(1, 0); // Fix some unknown problem
    scroll_pos_shift = 255;
    menu_line_print(mode_menu_pointers[irrigation_mode], 0);
    menu_line_print(mode_menu_pointers[irrigation_mode], 1);
    lcd_gotoxy(0,scroll_pos);
    lcd_putc(0); // Print cursor >
    shift_buffer[MENU_TEXT_SIZE_D - 1] = 0x7e;
}
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
int main(void)
{
    //Initialize rele
    *pump_ddr |= (1<<pump_gpio); // DDR set as output
    *pump_port |= (1 << pump_gpio); // set rele off
    // Initialize UART to asynchronous, 8N1, 9600
    uart_init(UART_BAUD_SELECT(9600, F_CPU));
    //Initialize sensors
    level_sens_init();
    sei();
    rtc_init();
    // Initialize LCD display
    lcd_init(LCD_DISP_ON);
    // Upload custom characters
    lcd_command(1 << LCD_CGRAM);
    for (uint8_t i = 0; i < sizeof(customChar); i++)
    {
        lcd_data(customChar[i]);
    }
    lcd_command(1 << LCD_DDRAM);
    // Print debug info about the menu
    lcd_gotoxy(0, 0);
    char str[16] = "                ";
    itoa(mode_menu_lenght[1], str, 10);
    lcd_puts(str);
    // Print the custom characters on display
    lcd_gotoxy(0, 1);
    for (uint8_t i = 0; i < sizeof(customChar)/8; i++)
    {
        lcd_putc(i);
    }    
    pump_start(); // Test the rele
    _delay_ms(1000);
    pump_stop();
    if(rtc_is_clock_running() == 0){
        rtc_set_time_s(12, 0, 0); // The clock is not running so set the time to default.
    }
    // Configure ADC to convert PC0[A0] analog value
    // Set ADC reference to AVcc
    ADMUX |= (1 << REFS0);
    // Set input channel to ADC0
    ADMUX &= ~((1 << MUX0) | (1 << MUX1) | (1 << MUX2) | (1 << MUX3));
    // Enable ADC module
    ADCSRA |= (1 << ADEN);
    // Enable conversion complete interrupt
    ADCSRA |= (1 << ADIE);
    // Set clock prescaler to 128
    ADCSRA |= (1 << ADPS2) | (1 << ADPS1) | (1 << ADPS0);
    // Configure 8-bit Timer/Counter2 to start ADC conversion
    // Set prescaler to 16 ms and enable overflow interrupt
    TIM2_overflow_16ms();
    TIM2_overflow_interrupt_enable();
    // Configure 16-bit Timer/Counter1 to start sensors readout
    // Set prescaler to 1 s and enable overflow interrupt
    TIM1_overflow_1s();
    TIM1_overflow_interrupt_enable();
    // Initialize sensors
    hum_init();
    level_sens_init();
    uint8_t key_press = 0; // variable for storing key presses
    display_menu(0); // Display menu before any user input
    // Infinite loop
    while (1) {
        TIM2_routine();
        TIM1_routine();
        key_press = key_press_detect(&ADC_key_value);
        if (key_press) { // if key is pressed
            TIM2_display_timer = 0; // reset inactivity timeout of menu
            char str[1] = "0";
            itoa(key_press, str, 10);
            uart_puts("\n\rKey pressed: ");
            uart_puts(str); // log to uart
            display_menu(key_press); // show menu
        }
        if(TIM2_display_timer > MENU_TIMEOUT_NUM){
            scroll_pos_shift = 255; //stop text shift
            TIM2_display_timer = MENU_TIMEOUT_NUM;
            if(display_update < 3){
                display_update = 4;
            }
            display_status(); // show screen
        }
    }

    // Will never reach this
    return 0;
}

/* Interrupt service routines ----------------------------------------*/
/**
 * @brief	Timer/Counter1 overflow interrupt
 * @details	Use single conversion mode and start.
 */
ISR(TIMER1_OVF_vect)
{
    // Signal to main
    TIM1_flag++;
}
/**
 * @brief	Timer/Counter2 overflow interrupt
 * @details	Use single conversion mode and start.
 */
ISR(TIMER2_OVF_vect)
{
    // Signal to main
    TIM2_flag++;
    TIM2_display_timer++;
    // Start ADC conversion
    ADCSRA |= (1 << ADSC);
}

/**
 * @brief	ADC complete interrupt
 * @details	Copy ADC value.
 */
ISR(ADC_vect) 
{
    ADC_key_value = ADC;  
}

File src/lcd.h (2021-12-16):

#ifndef LCD_H
# define LCD_H

/*************************************************************************
 * Title	:   C include file for the HD44780U LCD library (lcd.c)
 * Author:    Peter Fleury <pfleury@gmx.ch>  http://tinyurl.com/peterfleury
 * File:	    $Id: lcd.h,v 1.14.2.4 2015/01/20 17:16:07 peter Exp $
 * Software:  AVR-GCC 4.x
 * Hardware:  any AVR device, memory mapped mode only for AVR with
 *          memory mapped interface (AT90S8515/ATmega8515/ATmega128)
 ***************************************************************************/

/**
 * @ingroup lcd
 * @file lcd.h
 * @brief Consist rutines for LCD display interaction
 * @defgroup pfleury_lcd LCD library <lcd.h>
 * @code #include <lcd.h> @endcode
 *
 * @brief Basic routines for interfacing a HD44780U-based character LCD display
 *
 * LCD character displays can be found in many devices, like espresso machines, laser printers.
 * The Hitachi HD44780 controller and its compatible controllers like Samsung KS0066U have become an industry standard for these types of displays.
 *
 * This library allows easy interfacing with a HD44780 compatible display and can be
 * operated in memory mapped mode (LCD_IO_MODE defined as 0 in the include file lcd.h.) or in
 * 4-bit IO port mode (LCD_IO_MODE defined as 1). 8-bit IO port mode is not supported.
 *
 * Memory mapped mode is compatible with old Kanda STK200 starter kit, but also supports
 * generation of R/W signal through A8 address line.
 *
 * @see The chapter <a href=" http://homepage.hispeed.ch/peterfleury/avr-lcd44780.html" target="_blank">Interfacing a HD44780 Based LCD to an AVR</a>
 *    on my home page, which shows example circuits how to connect an LCD to an AVR controller.
 *
 * @author Peter Fleury pfleury@gmx.ch http://tinyurl.com/peterfleury
 *
 * @version   2.0
 *
 * @copyright (C) 2015 Peter Fleury, GNU General Public License Version 3
 *
 */

#include <inttypes.h>
#include <avr/pgmspace.h>

#if (__GNUC__ * 100 + __GNUC_MINOR__) < 405
# error "This library requires AVR-GCC 4.5 or later, update to newer AVR-GCC compiler !"
#endif


/**@{*/

/*
 * LCD and target specific definitions below can be defined in a separate include file with name lcd_definitions.h instead modifying this file
 * All definitions added to the file lcd_definitions.h will override the default definitions from lcd.h
 */
#include "lcd_definitions.h"


/**
 * @name  Definition for LCD controller type
 * Use 0 for HD44780 controller, change to 1 for displays with KS0073 controller.
 */
#ifndef LCD_CONTROLLER_KS0073
# define LCD_CONTROLLER_KS0073 0 /**< Use 0 for HD44780 controller, 1 for KS0073 controller */
#endif

/**
 * @name  Definitions for Display Size
 * Change these definitions to adapt setting to your display
 *
 * These definitions can be defined in a separate include file \b lcd_definitions.h instead modifying this file by
 * adding -D_LCD_DEFINITIONS_FILE to the CDEFS section in the Makefile.
 * All definitions added to the file lcd_definitions.h will override the default definitions from lcd.h
 *
 */
#ifndef LCD_LINES
# define LCD_LINES 2 /**< number of visible lines of the display */
#endif
#ifndef LCD_DISP_LENGTH
# define LCD_DISP_LENGTH 16 /**< visibles characters per line of the display */
#endif
#ifndef LCD_LINE_LENGTH
# define LCD_LINE_LENGTH 0x40 /**< internal line length of the display    */
#endif
#ifndef LCD_START_LINE1
# define LCD_START_LINE1 0x00 /**< DDRAM address of first char of line 1 */
#endif
#ifndef LCD_START_LINE2
# define LCD_START_LINE2 0x40 /**< DDRAM address of first char of line 2 */
#endif
#ifndef LCD_START_LINE3
# define LCD_START_LINE3 0x14 /**< DDRAM address of first char of line 3 */
#endif
#ifndef LCD_START_LINE4
# define LCD_START_LINE4 0x54 /**< DDRAM address of first char of line 4 */
#endif
#ifndef LCD_WRAP_LINES
# define LCD_WRAP_LINES 0 /**< 0: no wrap, 1: wrap at end of visibile line */
#endif


/**
 * @name Definitions for 4-bit IO mode
 *
 * The four LCD data lines and the three control lines RS, RW, E can be on the
 * same port or on different ports.
 * Change LCD_RS_PORT, LCD_RW_PORT, LCD_E_PORT if you want the control lines on
 * different ports.
 *
 * Normally the four data lines should be mapped to bit 0..3 on one port, but it
 * is possible to connect these data lines in different order or even on different
 * ports by adapting the LCD_DATAx_PORT and LCD_DATAx_PIN definitions.
 *
 * Adjust these definitions to your target.\n
 * These definitions can be defined in a separate include file \b lcd_definitions.h instead modifying this file by
 * adding \b -D_LCD_DEFINITIONS_FILE to the \b CDEFS section in the Makefile.
 * All definitions added to the file lcd_definitions.h will override the default definitions from lcd.h
 *
 */
#define LCD_IO_MODE 1 /**< 0: memory mapped mode, 1: IO port mode */

#if LCD_IO_MODE

# ifndef LCD_PORT
#  define LCD_PORT PORTA /**< port for the LCD lines   */
# endif
# ifndef LCD_DATA0_PORT
#  define LCD_DATA0_PORT LCD_PORT /**< port for 4bit data bit 0 */
# endif
# ifndef LCD_DATA1_PORT
#  define LCD_DATA1_PORT LCD_PORT /**< port for 4bit data bit 1 */
# endif
# ifndef LCD_DATA2_PORT
#  define LCD_DATA2_PORT LCD_PORT /**< port for 4bit data bit 2 */
# endif
# ifndef LCD_DATA3_PORT
#  define LCD_DATA3_PORT LCD_PORT /**< port for 4bit data bit 3 */
# endif
# ifndef LCD_DATA0_PIN
#  define LCD_DATA0_PIN 0 /**< pin for 4bit data bit 0  */
# endif
# ifndef LCD_DATA1_PIN
#  define LCD_DATA1_PIN 1 /**< pin for 4bit data bit 1  */
# endif
# ifndef LCD_DATA2_PIN
#  define LCD_DATA2_PIN 2 /**< pin for 4bit data bit 2  */
# endif
# ifndef LCD_DATA3_PIN
#  define LCD_DATA3_PIN 3 /**< pin for 4bit data bit 3  */
# endif
# ifndef LCD_RS_PORT
#  define LCD_RS_PORT LCD_PORT /**< port for RS line         */
# endif
# ifndef LCD_RS_PIN
#  define LCD_RS_PIN 4 /**< pin  for RS line         */
# endif
# ifndef LCD_RW_PORT
#  define LCD_RW_PORT LCD_PORT /**< port for RW line         */
# endif
# ifndef LCD_RW_PIN
#  define LCD_RW_PIN 5 /**< pin  for RW line         */
# endif
# ifndef LCD_E_PORT
#  define LCD_E_PORT LCD_PORT /**< port for Enable line     */
# endif
# ifndef LCD_E_PIN
#  define LCD_E_PIN 6 /**< pin  for Enable line     */
# endif

#elif defined(__AVR_AT90S4414__) || defined(__AVR_AT90S8515__) || defined(__AVR_ATmega64__) || \
    defined(__AVR_ATmega8515__) || defined(__AVR_ATmega103__) || defined(__AVR_ATmega128__) || \
    defined(__AVR_ATmega161__) || defined(__AVR_ATmega162__)

/*
 * memory mapped mode is only supported when the device has an external data memory interface
 */
# define LCD_IO_DATA     0xC000 /* A15=E=1, A14=RS=1                 */
# define LCD_IO_FUNCTION 0x8000 /* A15=E=1, A14=RS=0                 */
# define LCD_IO_READ     0x0100 /* A8 =R/W=1 (R/W: 1=Read, 0=Write   */

#else // if LCD_IO_MODE
# error "external data memory interface not available for this device, use 4-bit IO port mode"

#endif // if LCD_IO_MODE
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

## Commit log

2021-12-11 Water level sensing lib
    Added lib for resistant wattersensing
2021-12-13 doc and 3dmodels
    [humidity_sensor_housing_lid.stl, humidity_sensor_housing_socket.stl, water_sensor_housing.stl]
2021-12-15 HW doc updated
    [humidity_sensor_housing_lid.stl, humidity_sensor_housing_socket.stl, water_sensor_housing.stl]
2021-12-15 add datasheets and pump picture
2021-12-15 Modify sensor libraries
2021-12-15 Implement status page when inactive. Sensors readout. TODO: display clear only when needed.
2021-12-16 When key is pressed on status page it now does nothing in the menu only switches to menu
2021-12-16 Add support for printing time
2021-12-16 Add rele control for pump.
2021-12-16 scheme add
    [Watter level sensor.kicad_pcb, Watter level sensor.sch]
